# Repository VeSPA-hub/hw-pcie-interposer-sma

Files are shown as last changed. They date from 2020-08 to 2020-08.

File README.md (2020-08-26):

# PCIe interposer

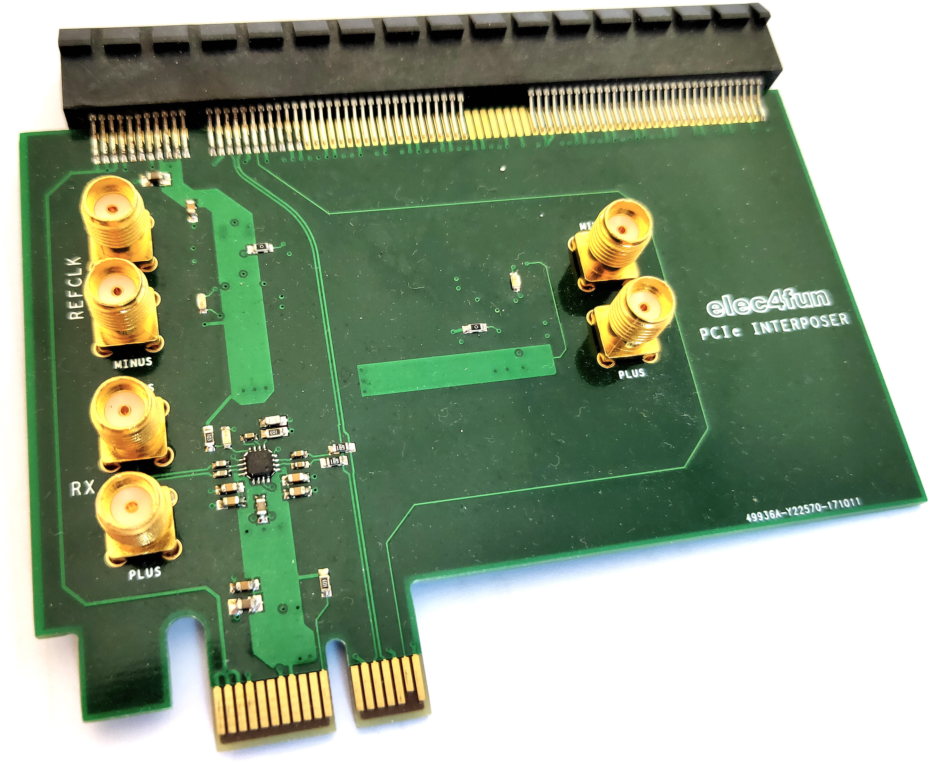
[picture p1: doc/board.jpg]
interposer


Board design files of a PCIe interposer with SMA outputs

	Note: This design was performed in Cadence Allegro / Capture
	Those are not open sources tools. This was before I started to work with KiCAD...

# Status

This version is fully tested.

# What it is

This board can tap PCIe signals (RX, TX and clock) and output them on SMA connectors.
Output signals can the be connected to some FPGA evaluation board for capture.
I did my tests with a Xilinx AC701.

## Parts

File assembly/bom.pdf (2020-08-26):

Item | Qty | Reference | NC | Value | Footprint | Manufacturer | Part number | Mouser ordering code
1 | 9 | C54, C56, C58, C65, C66, C69, C83, C84, C85 | | 10nF | 0402 | WALSIN | 0402B103K500CT | 791-0402B103K500CT
2 | 2 | C1, C4 | | 10µF | 0805 | TAIYO YUDEN | TMK212BBJ106MGHT | 963-TMK212BBJ106MGHT
3 | 6 | C55, C57, C67, C68, C76, C77 | | 100nF | 0402 | AVX | 0402YC104KAT2A | 581-0402YC104KAT2A
4 | 3 | C59, C70, C78 | | 18pF | 0603 | AVX | 06031A180JAT2A | 581-06031A180J
5 | 10 | C2 ,C3, C5, C6, C60, C62, C71, C73, C79, C81 | | 100nF | 0603 | KEMET | C0603C104K5RAC3121 | 80-C603C104K5RAC3121
6 | 6 | C61, C63, C72, C74, C80, C82 | | 1nF | 0603 | AVX | 06031C102JAT2A | 581-06031C102J
7 | 3 | C64, C75, C86 | | 10µF | 0603 | KEMET | C0603C106M9PACTU | 80-C0603C106M9P
8 | 3 | D4, D5, D6 | | LED GRN 0603 | 0603 | AVAGO TECHNOLOGIES | ASMT-RF45-AN002 | 630-ASMT-RF45-AN002
9 | 7 | R1, R20, R21, R25, R26, R27, R29 | | 10K | 0603 | YAGEO (PHYCOMP) | RC0603FR-0710KL | 603-RC0603FR-0710KL
10 | 6 | R17, R18, R22, R23, R30, R31 | | 680R | 0603 | VISHAY DRALORIC | CRCW0603680RFKEA | 71-CRCW0603-680-E3
11 | 3 | R19, R24, R28 | | 0R | 0603 | BOURNS | CR0603-J/-000ELF | 652-CR0603-J/-000ELF
12 | 1 | J1 | | PCIE CONNECTOR | - | AMPHENOL FCI | 10146027-A40010LF | 649-10146027A40010LF
13 | 6 | J2, J3, J4, J5, J6, J7 | | SMA | - | AMPHENOL RF | 132134 | 523-132134
14 | 3 | U2, U4, U6 | | ADN2891 | LFCSP-16 | ANALOG DEVICES | ADN2891ACPZ-RL7 | 584-ADN2891ACPZ-R7

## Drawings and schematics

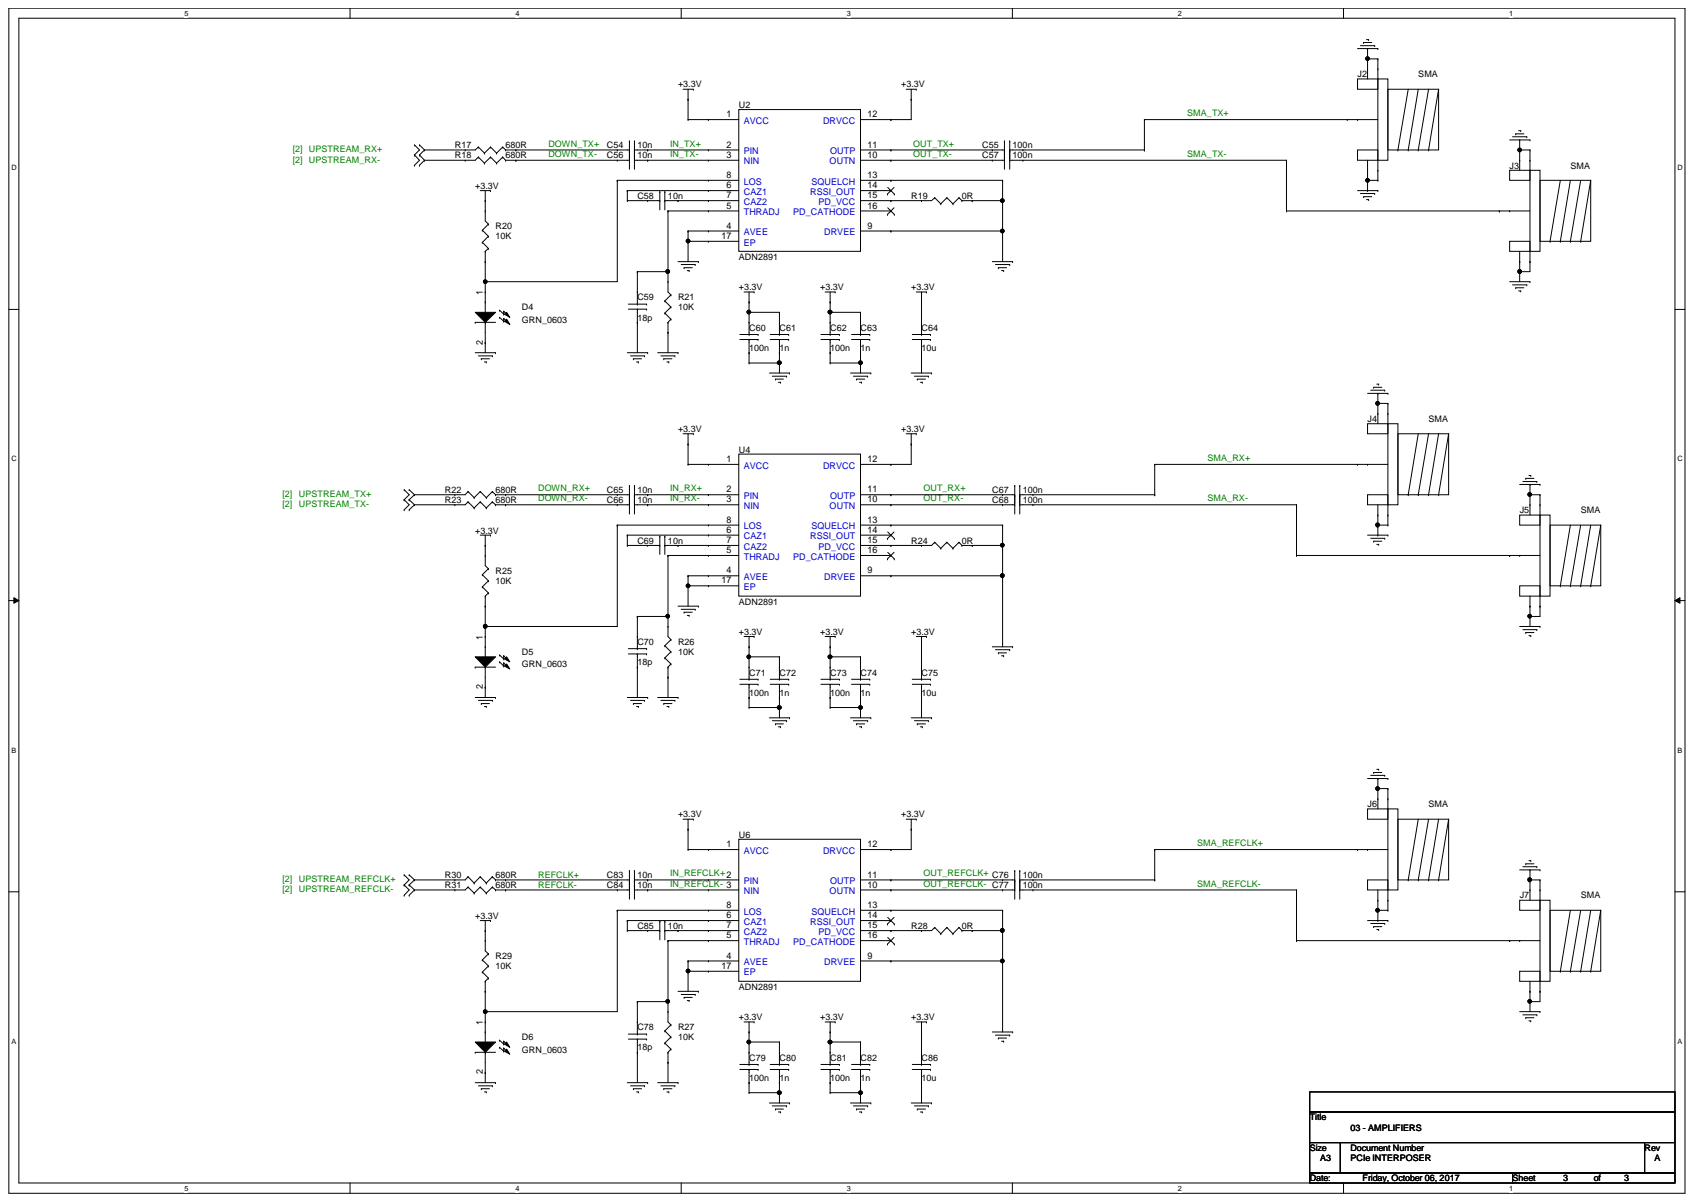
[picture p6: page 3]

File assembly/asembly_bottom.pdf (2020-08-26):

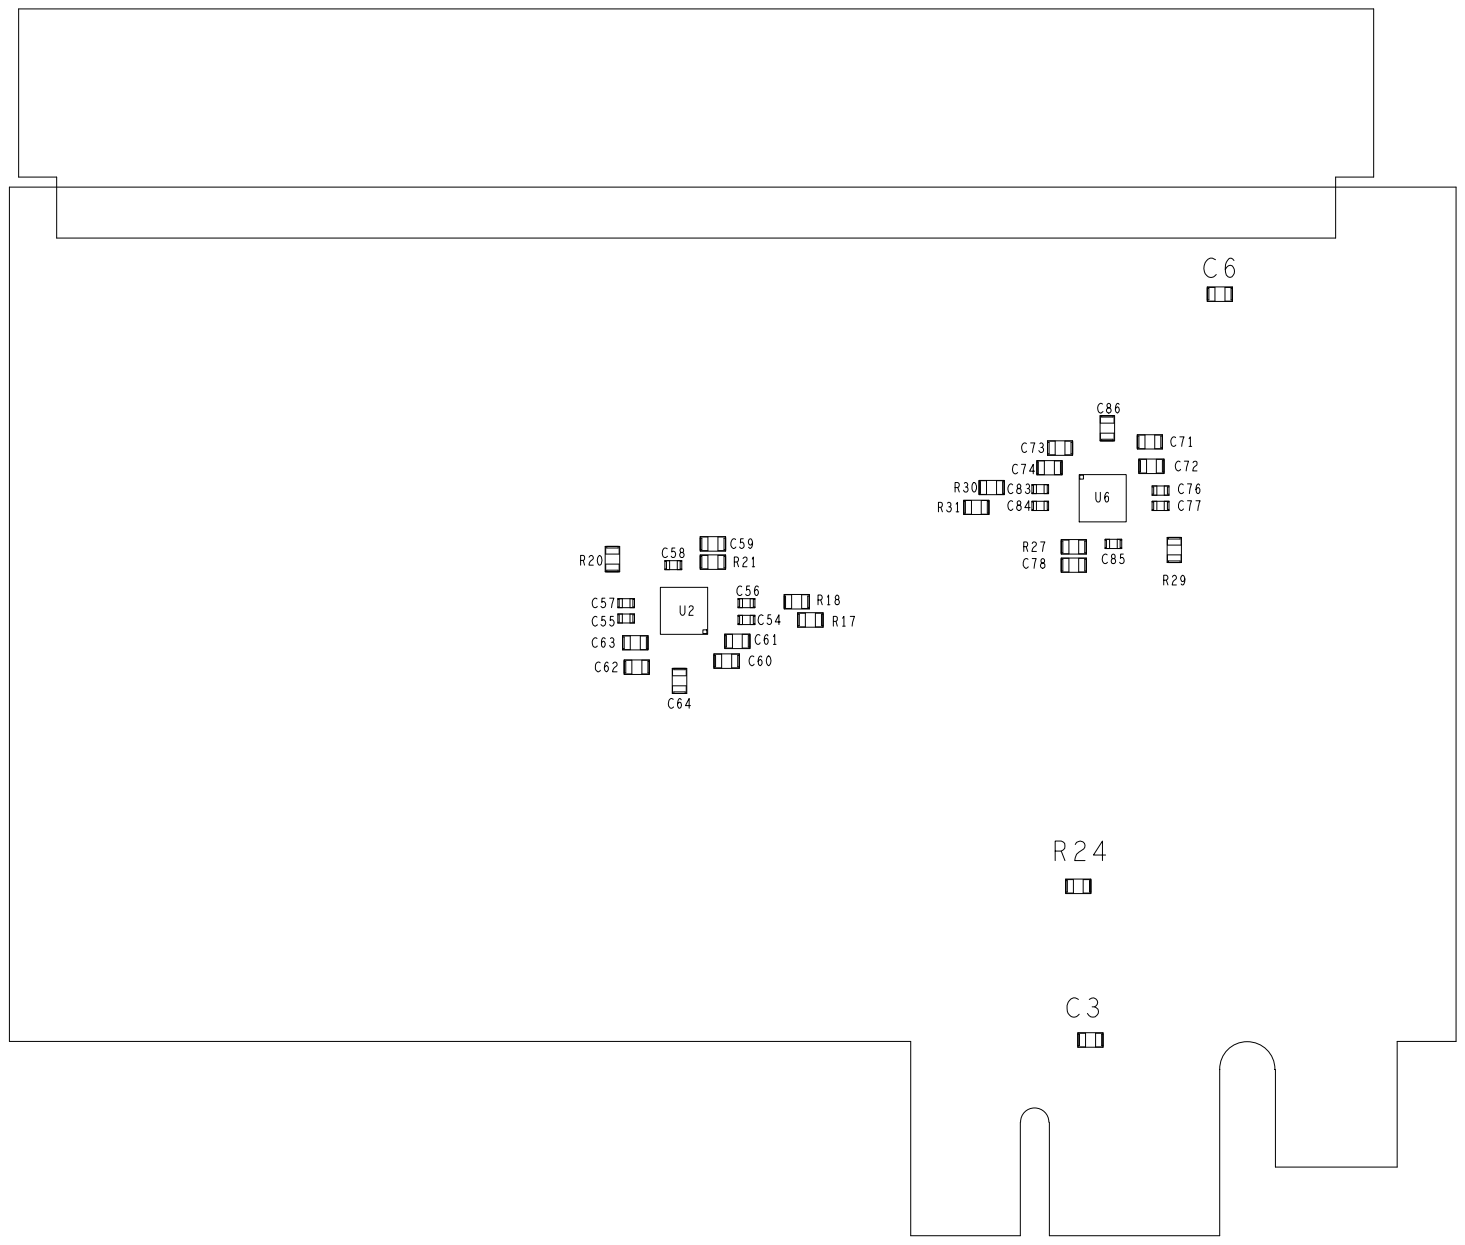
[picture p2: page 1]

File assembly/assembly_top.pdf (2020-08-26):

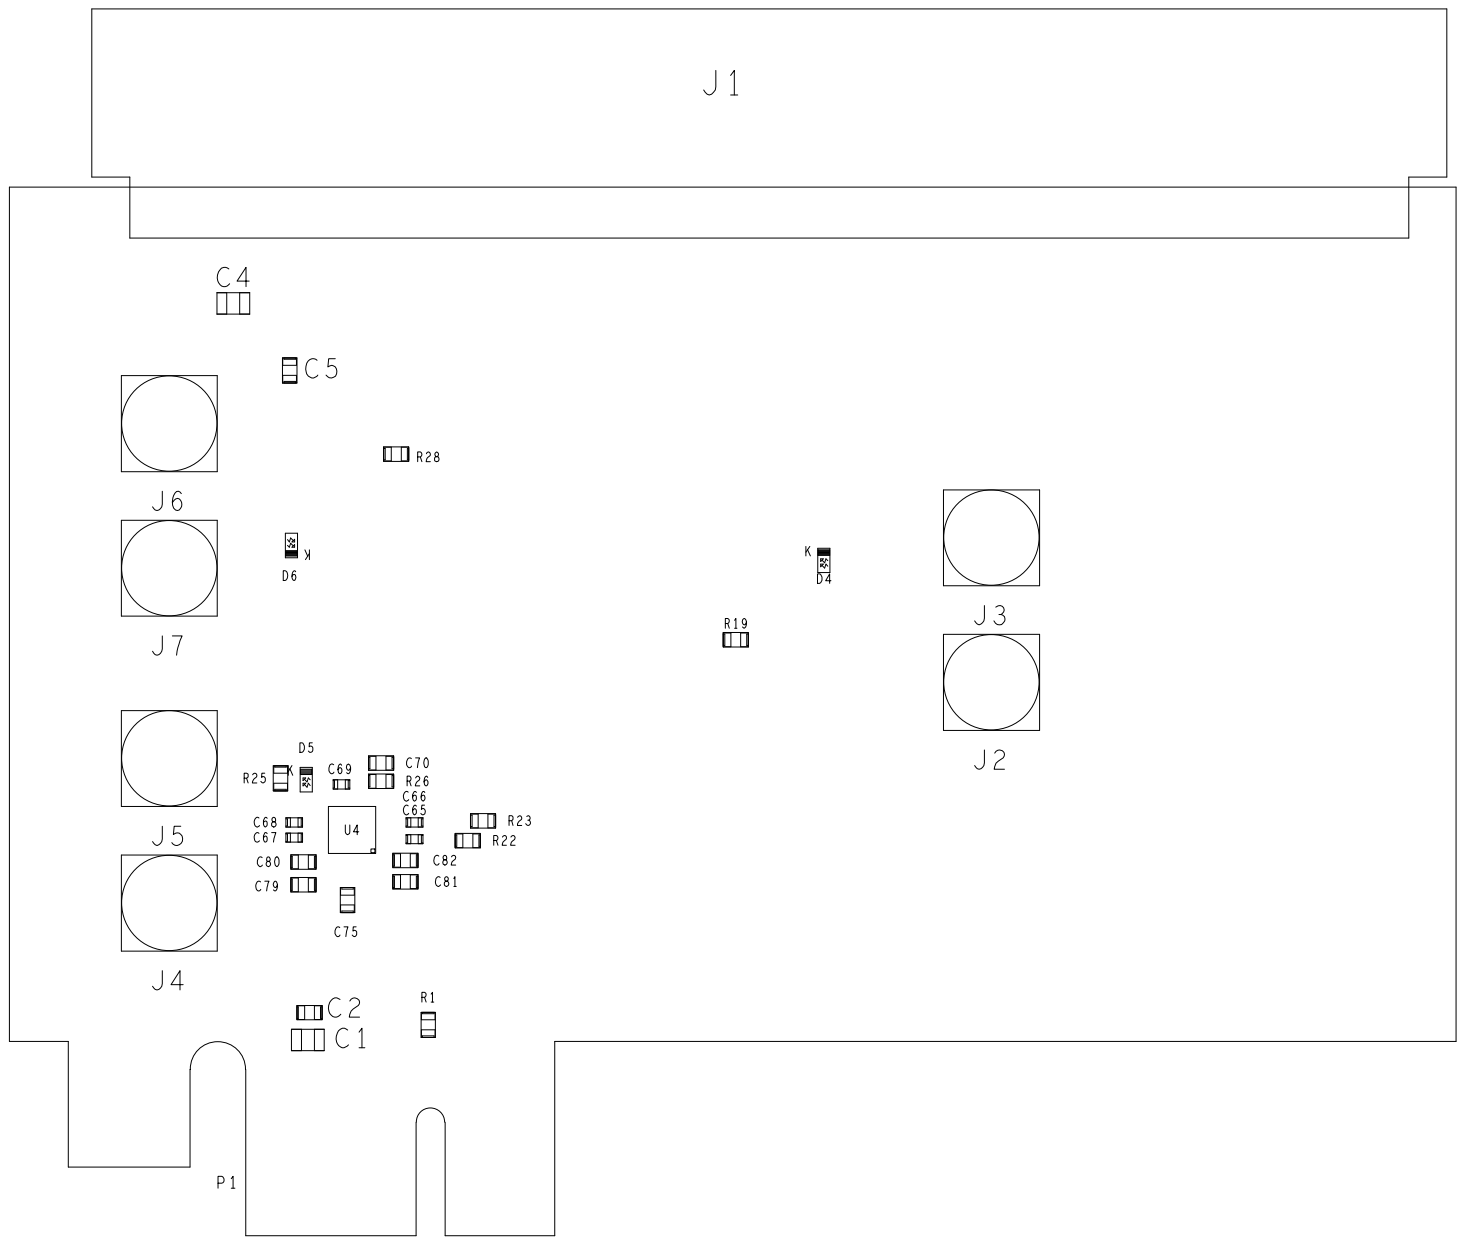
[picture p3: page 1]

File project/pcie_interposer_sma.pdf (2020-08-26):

# PCIe INTERPOSER - SMA

REVISION | DESCRIPTION | DATE

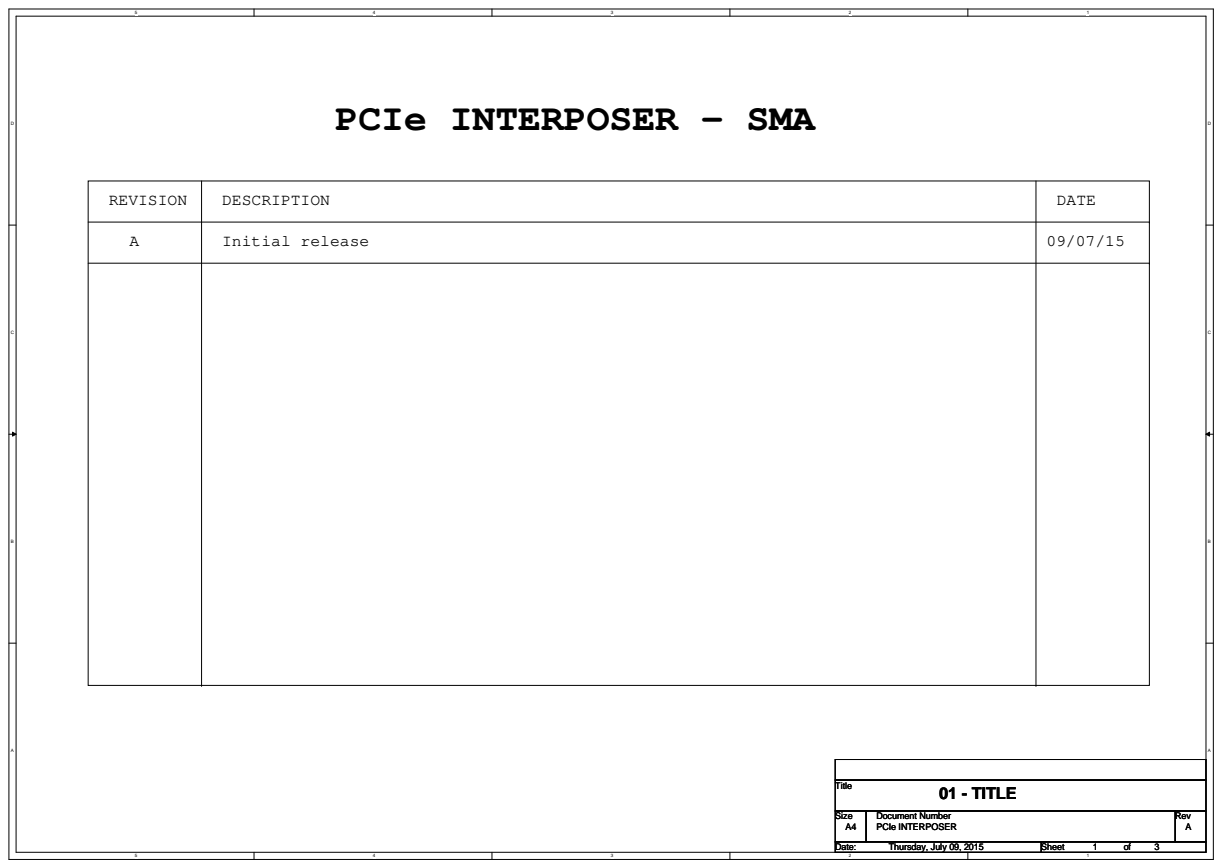
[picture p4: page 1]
Initial release; Title; Size; Document Number; Rev; Date:; Sheet; PCIe INTERPOSER; 01 - TITLE; Thursday, July 09, 2015

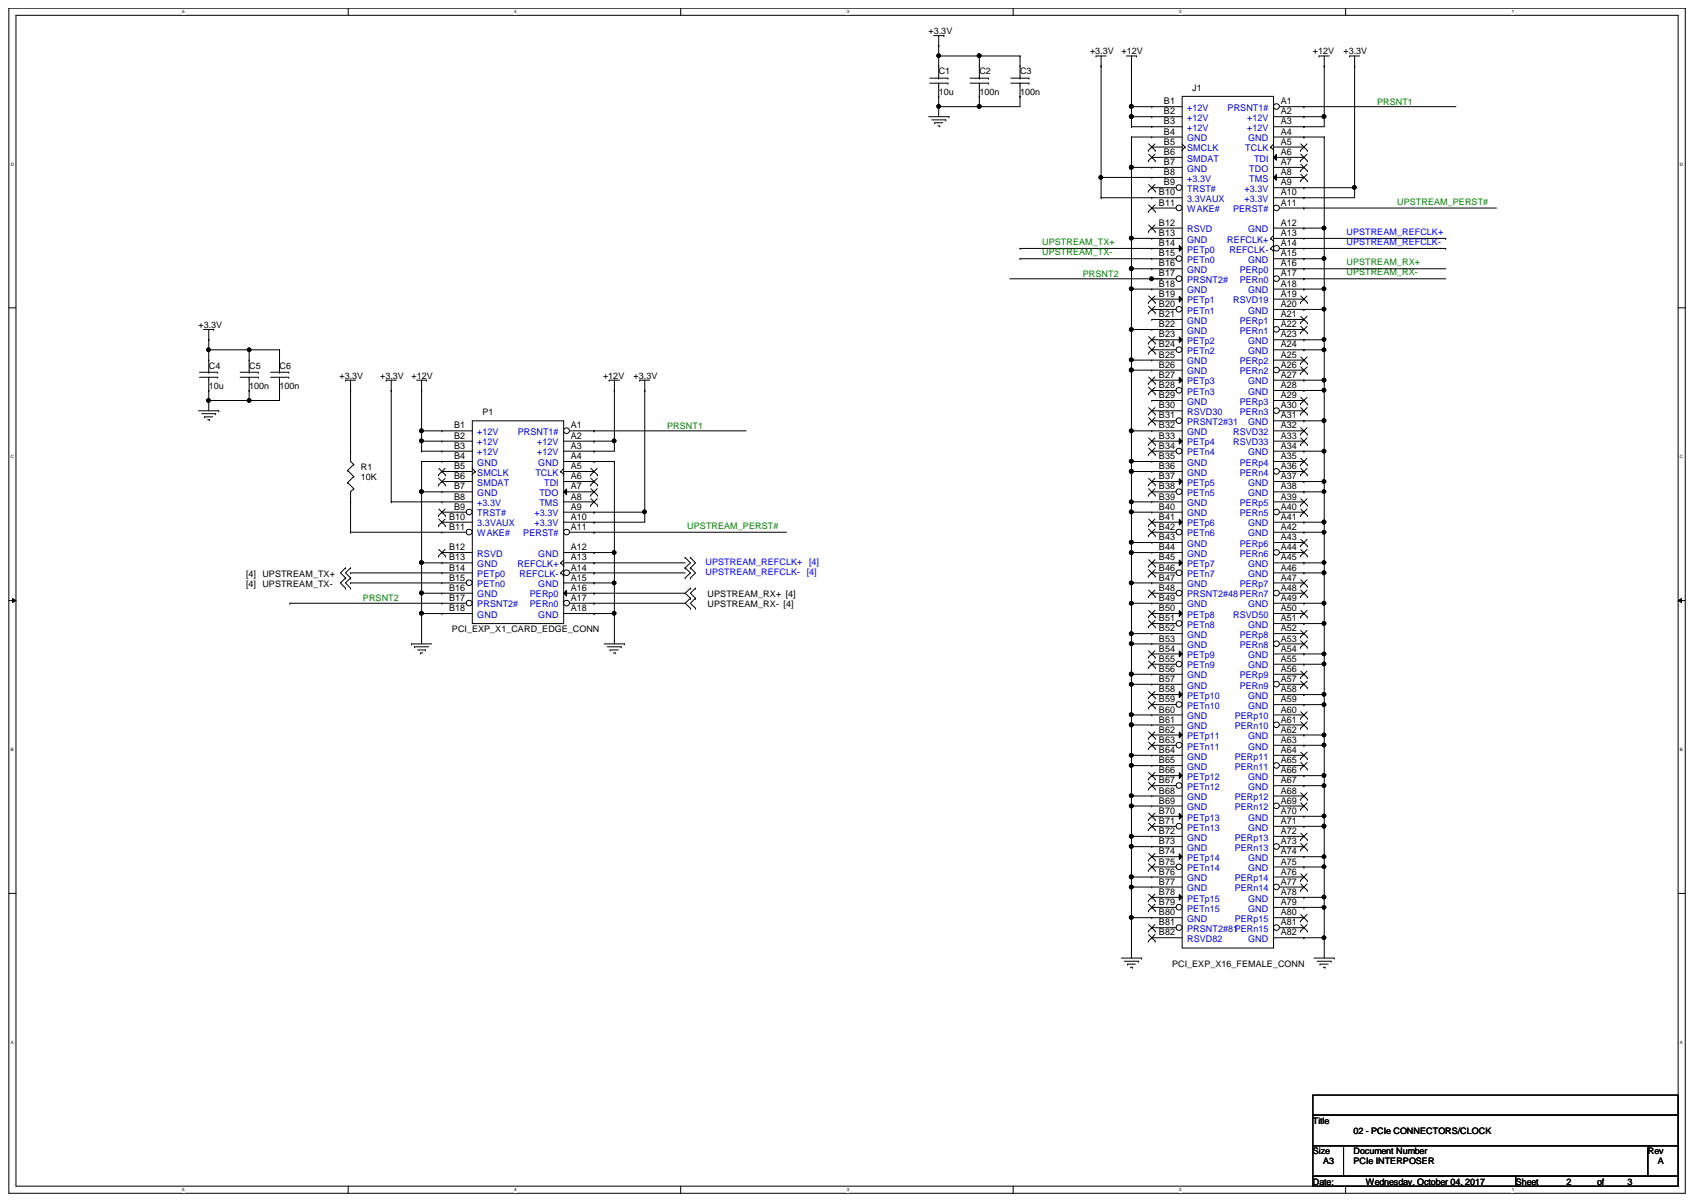
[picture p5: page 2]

# SMA_TX+ SMA_RX- SMA_RX+ SMA_REFCLK- SMA_REFCLK+
